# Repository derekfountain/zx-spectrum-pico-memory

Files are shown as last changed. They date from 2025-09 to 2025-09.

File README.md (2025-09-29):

# zx-spectrum-pico-memory

## A Microcontroller-based Lower Memory Implementation for the ZX Spectrum

This project replaces the 16K of lower memory in the ZX Spectrum with a Raspberry Pi Pico2. The RP2350
microcontoller on the Pico is programmed to emulate the original MK4116 DRAM ICs, and responds to reads
and writes from the Z80 CPU and the Spectrum's ULA support chip in the same way the original memory
does. It's not a cycle-perfect implementation, as I'll discuss, and to be honest it's of limited
practical use in this age of cheap SRAM based memory modules. But it was an interesting project, both
from a ZX point of view, and that of pushing the Pico to its limits.

### History

The original work on this project was done by myself and Andrew Menadue in 2022. Andrew designed the board
for the RP2040-based Raspberrry Pi Pico, and that work is still in
<a href="https://github.com/blackjetrock/zx-spectrum-pico-memory">his repository</a>. In late 2022 it
defeated us, the RP2040 just couldn't go fast enough to match 150ns silicon. I picked the project up
again in summer 2025 and had another look at it. Still unable to get it working, I changed it to use
the RP2350-based Pico2, and, that being a faster and more easily overclockable device, was able to
do the task. Just.

## The Technical Challenge

The MK4116 DRAM ICs in the ZX Spectrum provide the machine's lower 16K of RAM (memory locations 0x4000 to
0x7FFF inclusive). This memory area contains the memory used to create the Spectrum's memory mapped
video display (memory area 0x4000 to 0x5AFF inclusive). As such the 16K memory area is used by both the
Z80 CPU and the ULA support chip which is responsible for generating a video display from the memory
area.

The MK4116s used in the Spectrum are rated at 150ns, meaning a single read or write operation will
complete inside 150ns. Although the Z80 doesn't drive the DRAM ICs at their fastest speed, the ULA does.
This is because the ULA was tuned to generate the video image as quickly as possible, thereby not
slowing down the rest of the ZX Spectrum's system. The challenge with this DRAM emulator is to meet the
ULA's speed requirements, as opposed to the much more modest requirements of the Z80.

### Signal Patterns

The MK4116 was designed with a 7 bit address bus to meet physical space requirements and technical
limitations of the day, but to supply 16K of data it needs a 14 bit address bus. The solution to this
problem was to multiplex the address bus. The required 14 bits are sent from the Z80/ULA to the MK4116 in
two phases which make up a grid sort of pattern: the first 7 bits being supplied from the Z80/ULA as the "row"
and the second 7 bits being supplied from the Z80/ULA as the "column". Where the row and column intersect
in the internal MK4116 grid-like store, that's where the required data bit would be read from or written to.

The pattern for the MK4116 emulator to follow is therefore fairly simple: wait for the Row Address Strobe
(RAS) signal to appear, indicating the first 7 bits of the target address are on the address bus, then read
that value and store it. Then wait for the Column Address Strobe (CAS) signal to appear, indicating the
second 7 bits of the target address are on the address bus, then read that value and combine it with the
row value to get the full 14 bit address. Check the WRITE signal to see if the MK4116 should be doing a read
or write, and if it's a write go to the 8 bit data bus to fetch the value being written into the emulated
memory and write it into the Pico's onboard RAM. If the Z80/ULA is doing a read, go and fetch the data byte from
the Pico's onboard memory and put it on the data bus as an output. Once the Z80/ULA's done, go back to the top
and do it again.

The only real complication is that the MK4116 supports a "page mode" which the ULA (but not the Z80)
utilises. This is to support several reads in one go, and runs faster than the normal one-at-a-time mode.
In page mode, the RAS signal (and first 7 bits of the target addresses) are provided, and then the
repeated CAS signals (and associated second 7 bits of the target addresses) are provided one after the
other without ending the original RAS. It's a faster way of reading adjacent MK4116 memory and the ULA uses it to
build the video image as quickly as possible.

### Speed

The MK4116 may be a 1970s design, but it's still presented in silicon, which means it's fast. Not by today's
silicon standards maybe, but by todays CPU standards it is. The RP2040 natively runs at 133MHz, which means
one clock cycle is about 7.5 nanoseconds. The ARM chip runs approximately one instruction per clock cycle (it's
not quite that simple, but it's a rough approximation) which means it can run around 20 instructions in the
150ns access time of the original MK4116. So if the RP2040 was ever going to do everything required of it in
order to produce an accurate emulation, it was going to need to do it in very few instructions.

In pracise, 20 machine code instructions per transaction was never going to be enough to produce an emulation,
even of a simple storage device like the MK4116. Hefty overclocking was always going to be needed. Overclocking
to 270MHz might be fast enough.

It turned out that the RP2040-based Pico just wasn't fast enough. Back in 2022 when this project started I had
a particularly compliant one which overclocked to 360MHz, and that could run fast enough to satisfy the Z80's
requirements, but it was nowhere near fast enough to do the page mode reads the ULA needed. On this basis the
project stalled until 2025 when RP2350-based Pico2s became commonplace. All discussion and timings described
from this point onwards refer to the Pico2.

## Hardware

The hardware board was designed by Andrew Menadue. He did it based on the original Pico, the Pico2 not even
being discussed in 2022. It just fits inside the area of the Spectrum's PCB where the original MK4116s are
installed, and uses a handful of individual header pins to plug into the DRAM sockets.

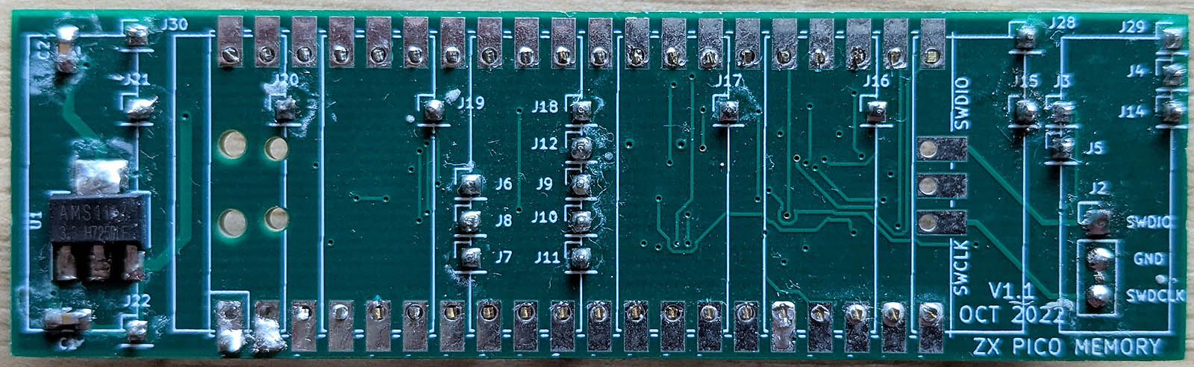
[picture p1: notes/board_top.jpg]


On the top of the board is a voltage regulator and the Raspberry Pi Pico (the photo above doesn't have the
Pico installed). On the underside, inside the area between the Pico's pins,
are 3 level shifters which convert the Spectrum's +5V signals to the Pico's +3V3 voltage. Input signals from 
the Spectrum, like RAS, CAS and the 7 address lines go through level shifters set to a single direction. The
data bus needs to be reversible, so the Pico can both read and write data byte values. The level shifter
which controls the data bus therefore has a Pico-controllable direction toggle.

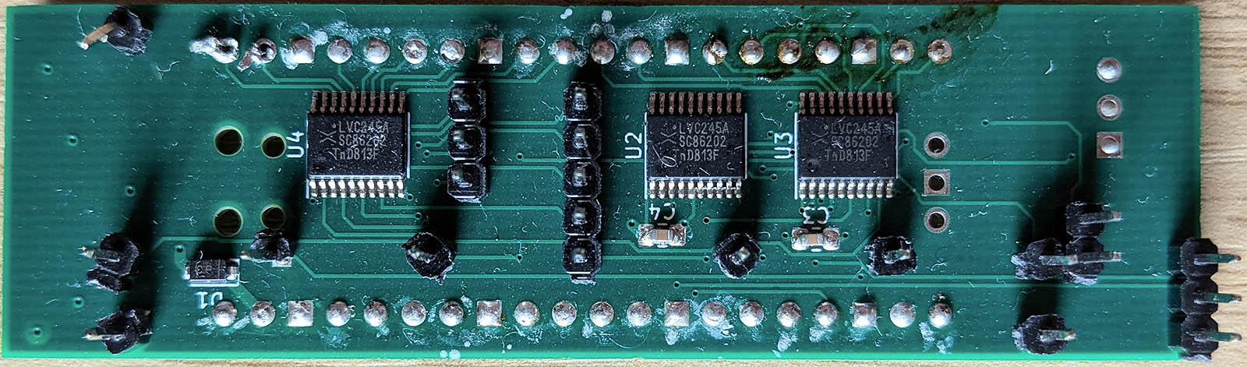
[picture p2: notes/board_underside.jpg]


It's a 4 layer board, and is still a bit cramped. The current version is too tall when the Pico is installed
on it, preventing the Spectrum's keyboard being fitted back in place. If anyone ever has a practical use for
this device it'll probably need redesigning so as to allow the Spectrum to be reassembled. Consider the
current board to be a functioning prototype.

## Software, and the outstanding issue

The software was the main challenge with this project. When Andrew and I started we worked together, writing
code in C. When it started to hit limitations Andrew branched off and started trying to write parts of the
main loop in ARM assembly language. I stuck with C code. We both managed to produce code which would meet
the speed requirements of the Z80:

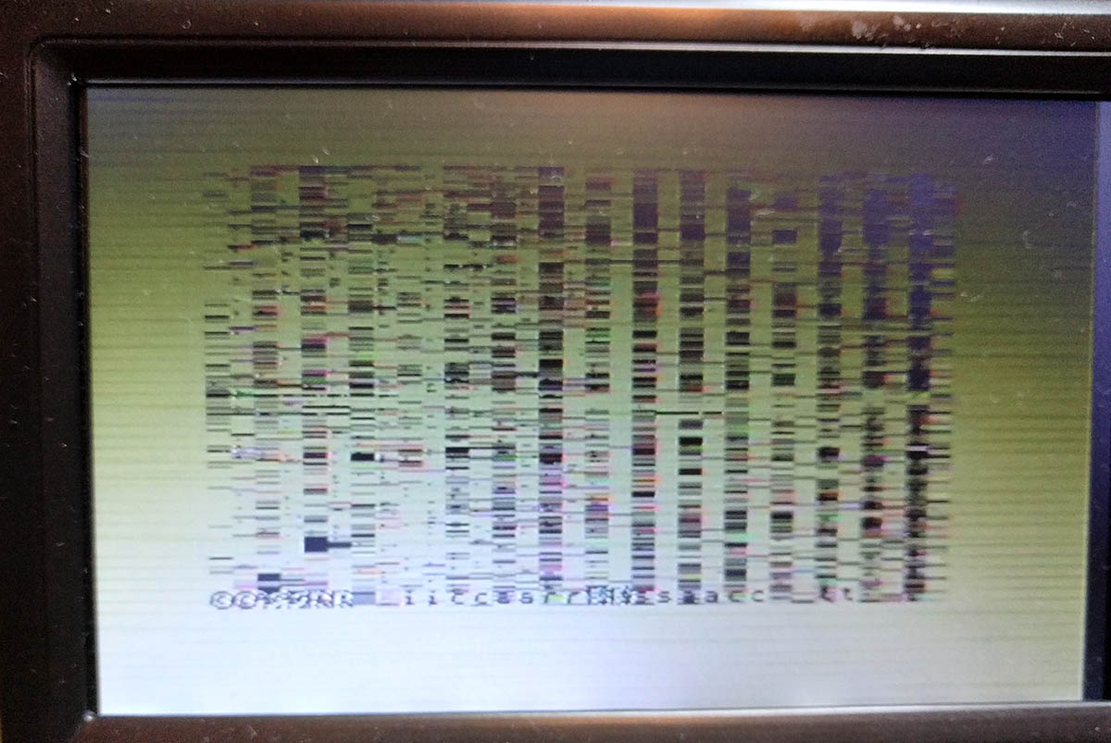
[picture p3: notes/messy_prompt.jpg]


You can just about see the (C) 1982 message peering out from that mess.

But despite a lot of effort, neither of us produced code fast enough to make the Spectrum work properly and
the project stalled for 3 years.

When the Pico2 came out, with its faster cores and higher clock speed I picked up the project and had another
look. I added a few optimisatons, but generally the code I tried on the RP2350 was much the same as that which
was failing on the RP2040 3 years earlier. Only, on the RP2350, with a little more tuning, it worked. Just about.

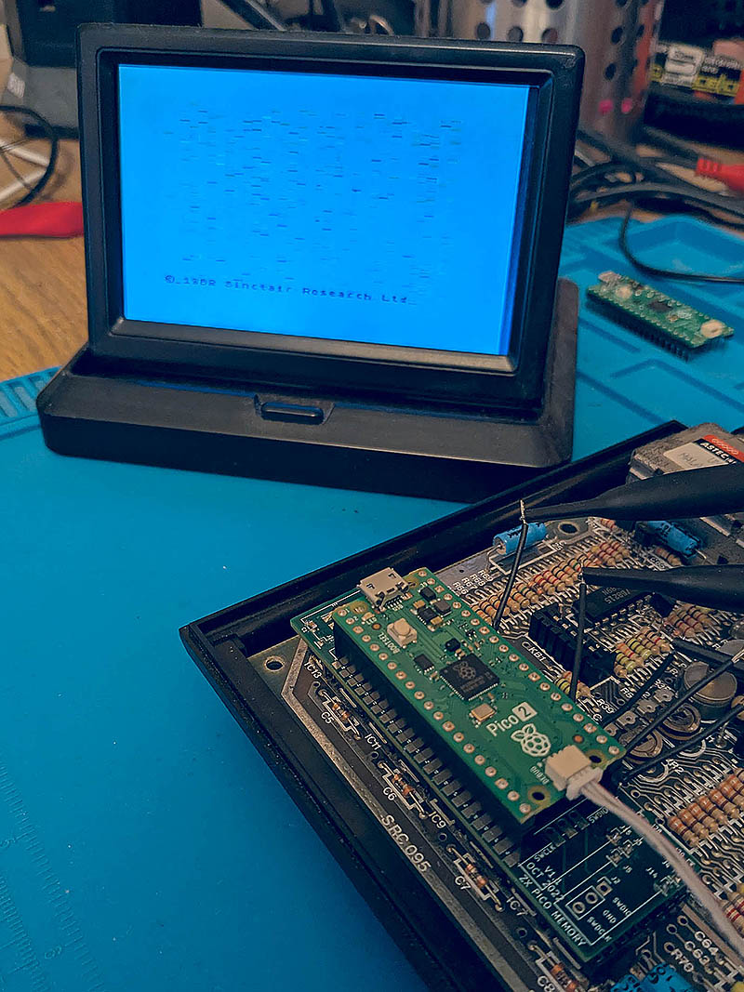
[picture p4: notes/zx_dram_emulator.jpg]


You can see on there are a number of flickering arefacts on the screen. Those are caused by the DRAM emulator
not running quite fast enough to deliver page mode reads to the ULA. Each artefact is the result of a missed
read, the ULA finding essentially random data on its data bus.

The problem is shown on the oscilloscope capture. Yellow is RAS, and that can be seen to go low at the left
side. CAS, in light blue, goes low twice, then RAS goes high again. Those 2 CAS signals indicate 2 data bytes
being read by the ULA, one for pixel data, the other for colour data. That bit works fine. So RAS then goes
high, and then low again. Shortly after RAS goes low the second time (yellow line, centre of the image) CAS
goes high then low again. That's where the ULA is reading the pixel data for the second time, and that's
where the problem is. The gap between RAS going low, and CAS going low, is very tight, about 100ns. At that
point the code needs to spot that RAS has gone low, get the 7 bits of row address from the address bus, then
get back to the top of the loop quickly enough in order to spot that CAS has gone low again. Most times it
can manage it, but just occasionally it misses the CAS. That's when an artefact appears on screen.

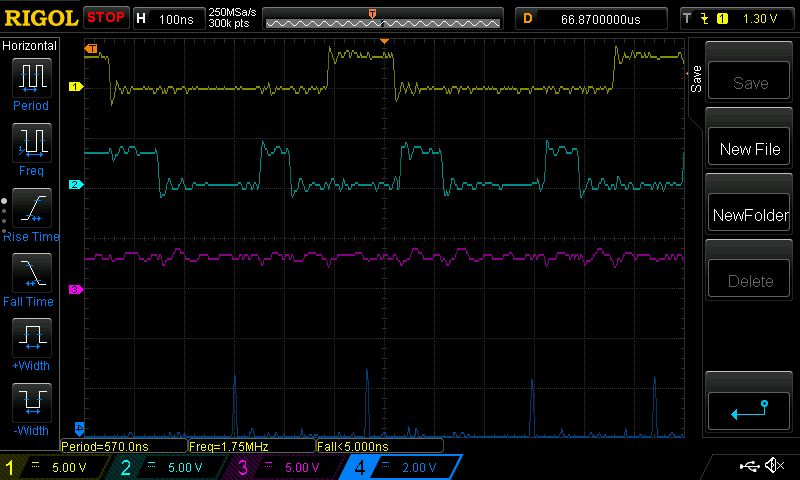
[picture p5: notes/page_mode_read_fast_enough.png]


So it's not quite good enough to use, and the software can't run any faster. PIOs might be an option to get
a bit more speed out of the emulator. Other than that we need to wait for Pico3. :)

[Derek Fountain](https://www.derekfountain.org/), September 2025

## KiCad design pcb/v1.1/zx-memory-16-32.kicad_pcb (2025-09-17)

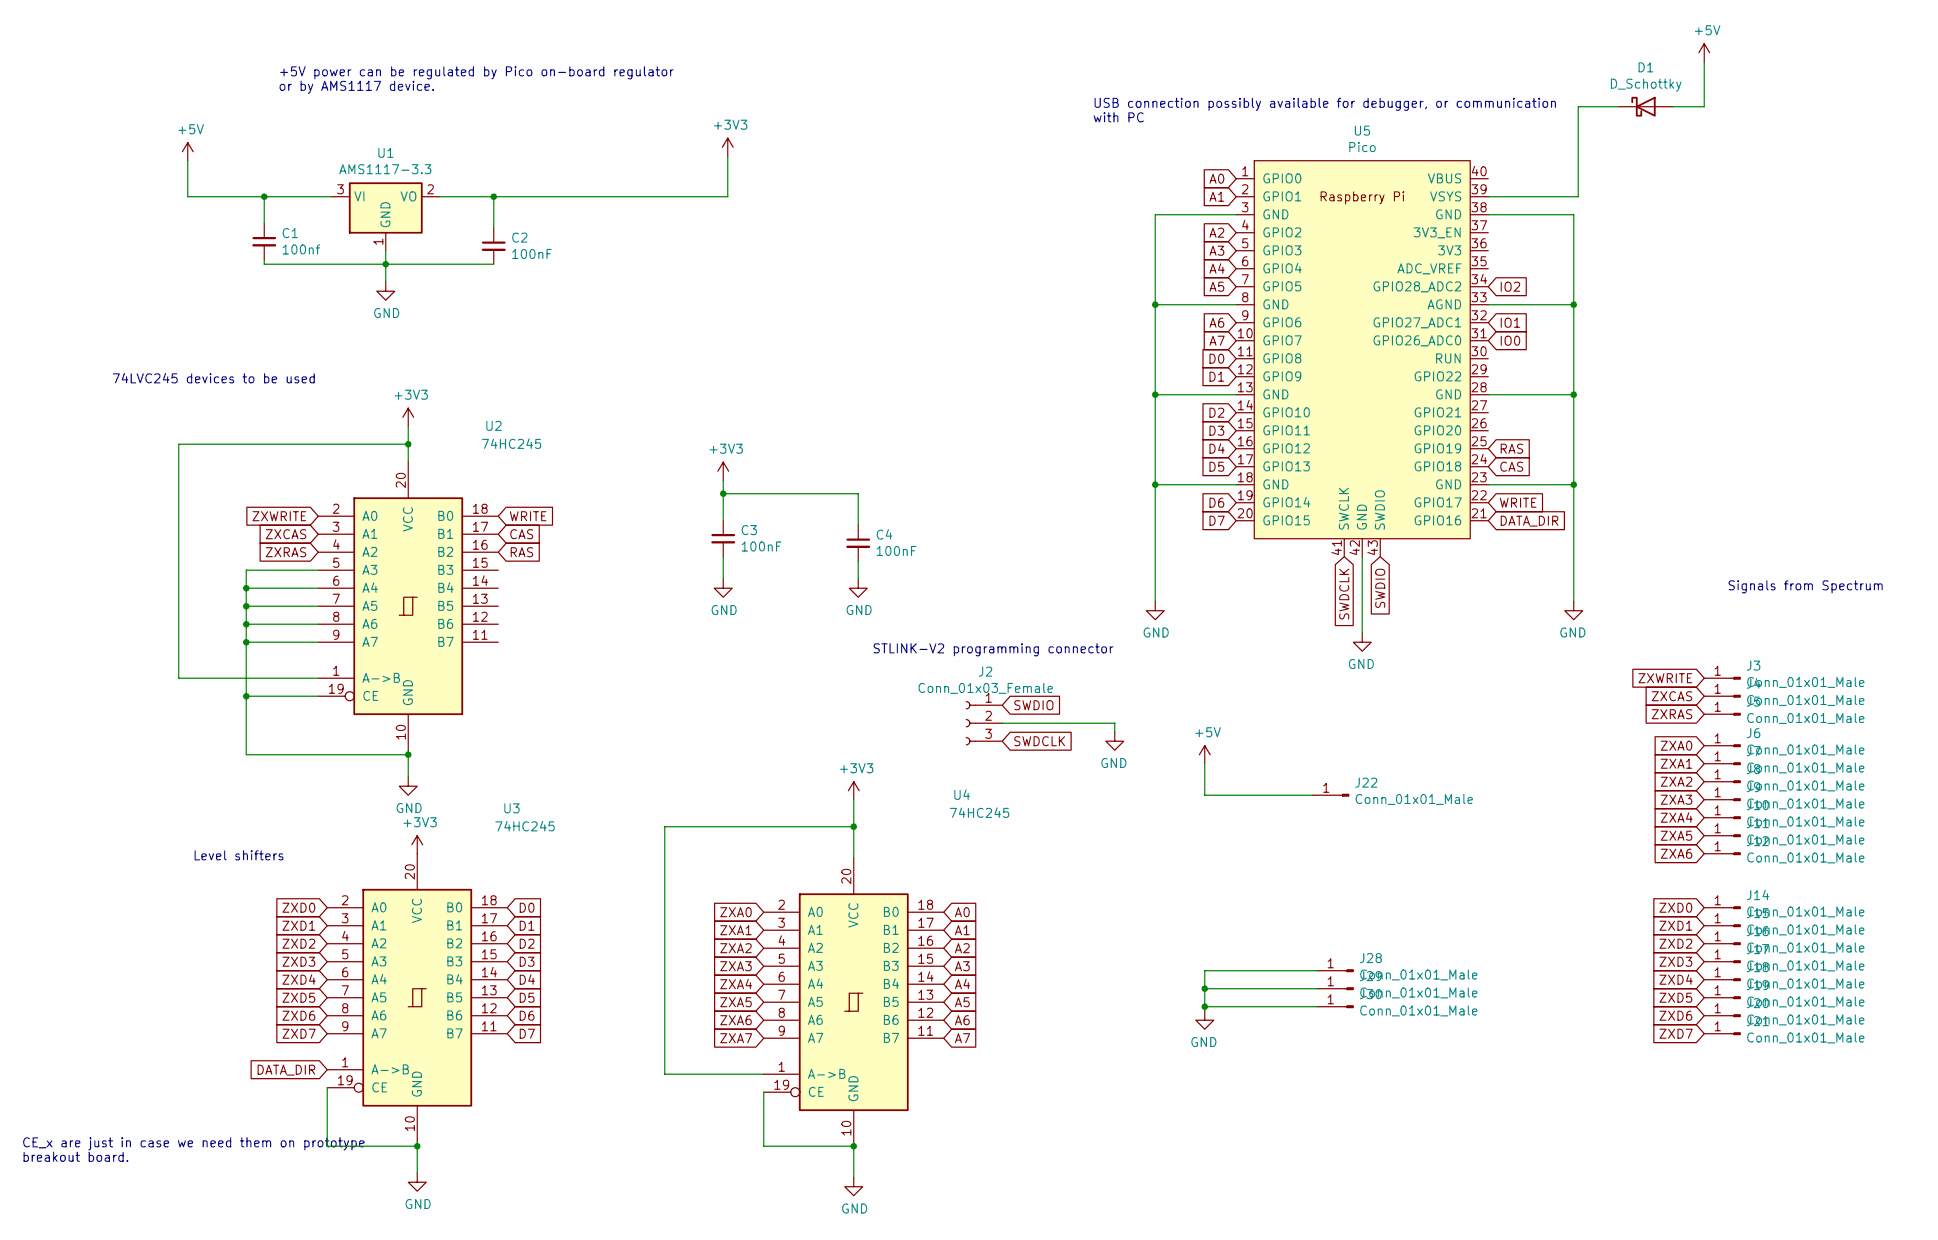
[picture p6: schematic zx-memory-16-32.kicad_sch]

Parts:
C1: 100nf; C_0805_2012Metric_Pad1.18x1.45mm_HandSolder
C2, C3, C4: 100nF; C_0805_2012Metric_Pad1.18x1.45mm_HandSolder
D1: D_Schottky; D_SOD-323_HandSoldering
J2: Conn_01x03_Female; PinHeader_1x03_P2.54mm_Vertical
J3, J4, J5, J6, J7, J8, J9, J10, J11, J12, J14, J15, J16, J17, J18, J19, J20, J21, J22, J28, J29, J30: Conn_01x01_Male; PinHeader_1x01_P2.00mm_Vertical
U1: AMS1117-3.3; SOT-223-3_TabPin2
U2, U3, U4: 74HC245; TSSOP-20_4.4x6.5mm_P0.65mm
U5: Pico; RPi_Pico_SMD_TH

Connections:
+3V3: C2.1, C3.1, C4.1, U1.2 (VO), U2.1 (A->B), U2.20 (VCC), U3.20 (VCC), U4.1 (A->B), U4.20 (VCC)
+5V: C1.1, D1.2 (A), J22.1, U1.3 (VI)
A0: U4.18 (B0), U5.1 (GPIO0)
A1: U4.17 (B1), U5.2 (GPIO1)
A2: U4.16 (B2), U5.4 (GPIO2)
A3: U4.15 (B3), U5.5 (GPIO3)
A4: U4.14 (B4), U5.6 (GPIO4)
A5: U4.13 (B5), U5.7 (GPIO5)
A6: U4.12 (B6), U5.9 (GPIO6)
A7: U4.11 (B7), U5.10 (GPIO7)
CAS: U2.17 (B1), U5.24 (GPIO18)
D0: U3.18 (B0), U5.11 (GPIO8)
D1: U3.17 (B1), U5.12 (GPIO9)
D2: U3.16 (B2), U5.14 (GPIO10)
D3: U3.15 (B3), U5.15 (GPIO11)
D4: U3.14 (B4), U5.16 (GPIO12)
D5: U3.13 (B5), U5.17 (GPIO13)
D6: U3.12 (B6), U5.19 (GPIO14)
D7: U3.11 (B7), U5.20 (GPIO15)
DATA_DIR: U3.1 (A->B), U5.21 (GPIO16)
GND: C1.2, C2.2, C3.2, C4.2, J2.2, J28.1, J29.1, J30.1, U1.1 (GND), U2.5 (A3), U2.6 (A4), U2.7 (A5), U2.8 (A6), U2.9 (A7), U2.10 (GND), U2.19 (CE), U3.10 (GND), U3.19 (CE), U4.10 (GND), U4.19 (CE), U5.3 (GND), U5.8 (GND), U5.13 (GND), U5.18 (GND), U5.23 (GND), U5.28 (GND), U5.33 (AGND), U5.38 (GND), U5.42 (GND)
IO0: U5.31 (GPIO26_ADC0)
IO1: U5.32 (GPIO27_ADC1)
IO2: U5.34 (GPIO28_ADC2)
unnamed: D1.1 (K), U5.39 (VSYS)
RAS: U2.16 (B2), U5.25 (GPIO19)
SWDCLK: J2.3, U5.41 (SWCLK)
SWDIO: J2.1, U5.43 (SWDIO)
WRITE: U2.18 (B0), U5.22 (GPIO17)
ZXA0: J6.1, U4.2 (A0)
ZXA1: J7.1, U4.3 (A1)
ZXA2: J8.1, U4.4 (A2)
ZXA3: J9.1, U4.5 (A3)
ZXA4: J10.1, U4.6 (A4)
ZXA5: J11.1, U4.7 (A5)
ZXA6: J12.1, U4.8 (A6)
ZXCAS: J4.1, U2.3 (A1)
ZXD0: J14.1, U3.2 (A0)
ZXD1: J15.1, U3.3 (A1)
ZXD2: J16.1, U3.4 (A2)
ZXD3: J17.1, U3.5 (A3)
ZXD4: J18.1, U3.6 (A4)
ZXD5: J19.1, U3.7 (A5)
ZXD6: J20.1, U3.8 (A6)
ZXD7: J21.1, U3.9 (A7)
ZXRAS: J5.1, U2.4 (A2)
ZXWRITE: J3.1, U2.2 (A0)

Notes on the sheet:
USB connection possibly available for debugger, or communication with PC
STLINK-V2 programming connector
Signals from Spectrum
+5V power can be regulated by Pico on-board regulator or by AMS1117 device.
CE_x are just in case we need them on prototype breakout board.
Level shifters
74LVC245 devices to be used

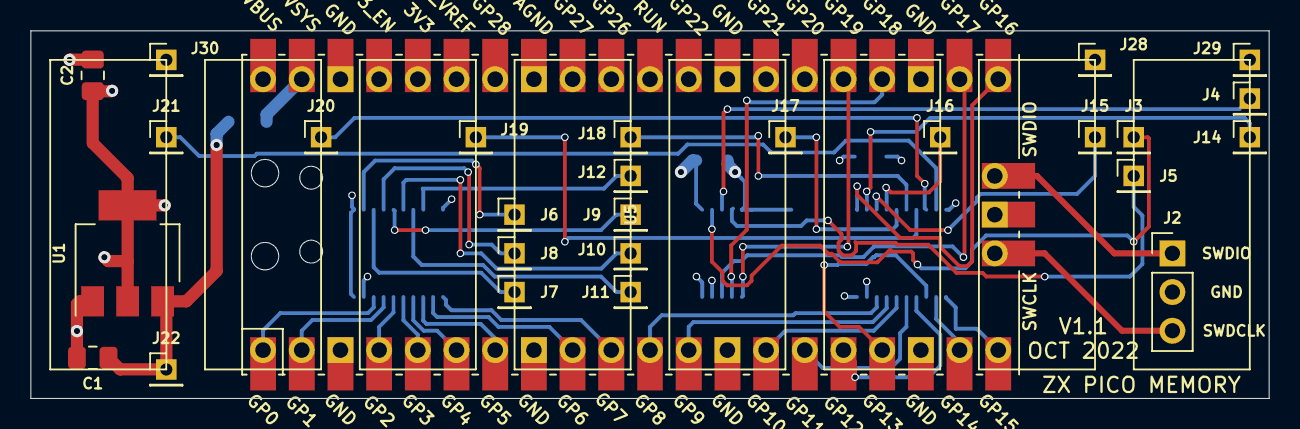
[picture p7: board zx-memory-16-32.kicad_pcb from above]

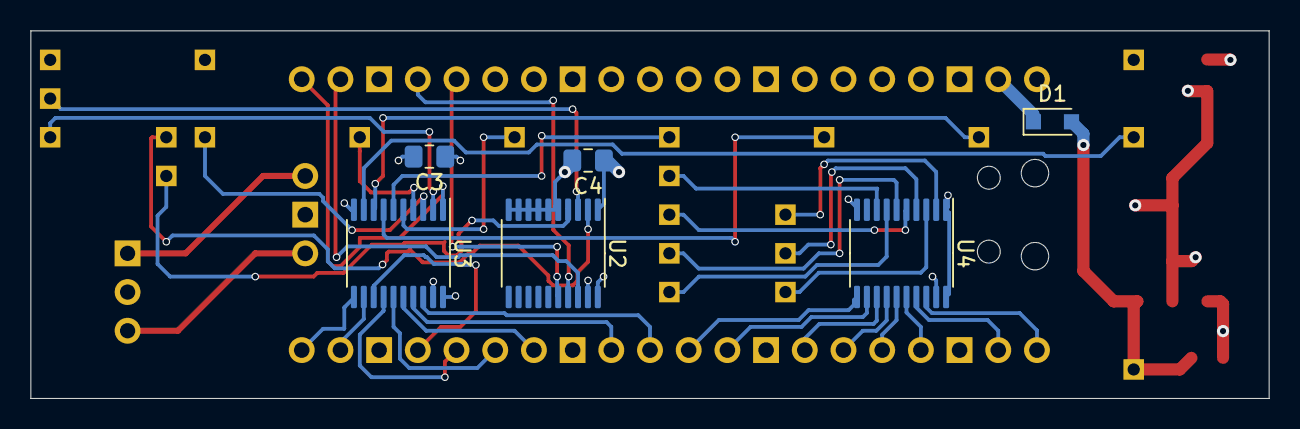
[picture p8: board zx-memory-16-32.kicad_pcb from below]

Board: 4 copper layers, 81.3 x 24.1 mm, 33 parts (6 on the bottom side), 44 nets.

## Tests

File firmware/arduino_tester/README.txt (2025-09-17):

Simulator, runs on an Arduino, outputs RAS, CAS and WR waveforms
in the same pattern as the Spectrum ULA. Only much slower.

Pattern is 4 reads in page mode, pause, 1 refresh, 1 read in cycle mode,
1 write in cycle mode.

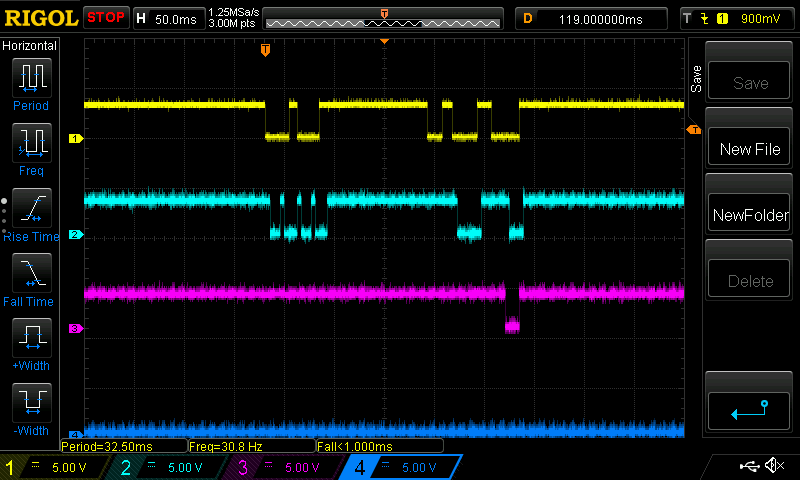
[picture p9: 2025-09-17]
firmware/arduino_tester/sim_output.png

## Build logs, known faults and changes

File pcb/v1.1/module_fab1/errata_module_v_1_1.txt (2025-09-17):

ZX Pico Memory Module V1.1 Errata

1. J22 is 0.1" too low and doesn't line up with the DRAM 5V pin. Bend pin
   to get it to fit.

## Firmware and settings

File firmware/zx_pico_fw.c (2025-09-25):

/*
 * ZX-Pico RAM Emulation, a Raspberry Pi Pico based Spectrum DRAM device
 * Copyright (C) 2025 Derek Fountain, Andrew Menadue
 * 
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
 * You should have received a copy of the GNU General Public License
 * along with this program; if not, write to the Free Software
 * Foundation, Inc., 51 Franklin Street, Fifth Floor, Boston, MA  02110-1301, USA.
 */

/*
 * export PICO_SDK_PATH=/home/derek/BEETLE/Derek/dev/Pico/pico-sdk-v2.x
 *
 * cmake -DPICO_BOARD=pico2 ..
 * cmake -DCMAKE_BUILD_TYPE=Debug -DPICO_BOARD=pico2 ..
 * make -j10
 *
 * sudo openocd -f interface/picoprobe.cfg -f target/rp2040.cfg -c "program ./pico1.elf verify reset exit"
 * sudo openocd -f interface/picoprobe.cfg -f target/rp2040.cfg
 * sudo openocd -f interface/cmsis-dap.cfg -f target/rp2350.cfg -c "adapter speed 5000" -c "program zx_pico_fw.elf verify reset exit"
 * sudo openocd -f interface/cmsis-dap.cfg -f target/rp2350.cfg -c "adapter speed 5000"
 *
 * gdb-multiarch ./pico1.elf
 *  target remote localhost:3333
 *  load
 *  monitor reset init
 *  continue
 */

/* 1 instruction on the 133MHz microprocessor is 7.5ns */
/* 1 instruction on the 200MHz microprocessor is 5.0ns */
/* 1 instruction on the 270MHz microprocessor is 3.7ns */
/* 1 instruction on the 360MHz microprocessor is 2.8ns */

//#define OVERCLOCK 200000
//#define OVERCLOCK 250000
//#define OVERCLOCK 270000
//#define OVERCLOCK 312000
#define OVERCLOCK 360000

/* I think a NOP on the RP2350 runs in half a clock cycle? */
#define _10_NOPS_  __asm volatile ("nop"); \
                   __asm volatile ("nop"); \
                   __asm volatile ("nop"); \
                   __asm volatile ("nop"); \
                   __asm volatile ("nop"); \
                   __asm volatile ("nop"); \
                   __asm volatile ("nop"); \
                   __asm volatile ("nop"); \
                   __asm volatile ("nop"); \
                   __asm volatile ("nop")


#include <stdio.h>
#include <stdint.h>
#include <string.h>
#include <stdlib.h>
#include "pico/stdlib.h"
#include "hardware/gpio.h"
#include "pico/binary_info.h"
#include "hardware/clocks.h"
#include "hardware/vreg.h"
#include "pico/multicore.h"

const uint8_t LED_PIN = PICO_DEFAULT_LED_PIN;

/* These pin values are the GPxx ones in green background on the pinout diagram */

/* Lowest 7 bits in the result from gpio_get_all() */
const uint8_t A0_GP         = 0;
const uint8_t A1_GP         = 1;
const uint8_t A2_GP         = 2;
const uint8_t A3_GP         = 3;
const uint8_t A4_GP         = 4;
const uint8_t A5_GP         = 5;
const uint8_t A6_GP         = 6;
/* A7 is currently unused but it's on the hardware design in case we ever need it */

const uint8_t D0_GP         = 8;
const uint8_t D1_GP         = 9;
const uint8_t D2_GP         = 10;
const uint8_t D3_GP         = 11;
const uint8_t D4_GP         = 12;
const uint8_t D5_GP         = 13;
const uint8_t D6_GP         = 14;
const uint8_t D7_GP         = 15;

const uint8_t RAS_GP        = 19;  /* GP19, pin 25 on Pico, 5th bottom one, on the right side */
const uint8_t CAS_GP        = 18;  /* GP18, pin 24 on Pico, 4th bottom one, on the right side */
const uint8_t WR_GP         = 17;  /* GP17, pin 22 on Pico, 2nd bottom one, on the right side */
const uint8_t DIR_GP        = 16;  /* GP16, pin 21 on Pico, bottom one, on the right side */

/* Keep the address bus in the lowest GPIOs so no rotation is required to read it */
const uint32_t ADDR_GP_MASK = (1<<A0_GP |
                               1<<A1_GP |
                               1<<A2_GP |
                               1<<A3_GP |
                               1<<A4_GP |
                               1<<A5_GP |
                               1<<A6_GP);

const uint32_t DBUS_GP_MASK = (1<<D0_GP |
                               1<<D1_GP |
                               1<<D2_GP |
                               1<<D3_GP |
                               1<<D4_GP |
                               1<<D5_GP |
                               1<<D6_GP |
                               1<<D7_GP);
const uint8_t  DBUS_ROTATE   = 8;

const uint32_t RAS_GP_MASK   = (1<<RAS_GP);
const uint32_t CAS_GP_MASK   = (1<<CAS_GP);
const uint32_t WR_GP_MASK    = (1<<WR_GP);
const uint32_t STROBE_MASK   = (RAS_GP_MASK | CAS_GP_MASK);
const uint32_t DIR_GP_MASK   = (1<<DIR_GP);

const uint8_t TEST_INPUT_GP  = 28;  /* Only use one of these */
const uint8_t TEST_OUTPUT_GP = 28;

/* 16K buffer to emulate the DRAM with */
#define STORE_SIZE 16384
uint32_t *store_ptr;

void __time_critical_func(core1_main)( void )
{
}

int main()
{
  bi_decl(bi_program_description("ZX Spectrum Lower memory Pico board binary."));

#ifdef OVERCLOCK
#if OVERCLOCK > 312000
  vreg_set_voltage(VREG_VOLTAGE_1_20);
  sleep_ms(1000);
#endif
#endif

#ifdef OVERCLOCK
  set_sys_clock_khz( OVERCLOCK, 1 );
#endif

  /* All interrupts off */
  irq_set_mask_enabled( 0xFFFFFFFF, 0 );

  /* All our GPIOs are inputs, except... */
  gpio_set_dir_in_masked( 0x1FFFFFFF );

  /* ...the data direction and my result blipper pin, which are outputs from the pico */
  gpio_init(DIR_GP);
  gpio_set_dir(DIR_GP, GPIO_OUT);
  gpio_set_slew_rate(DIR_GP, GPIO_SLEW_RATE_FAST);
  gpio_set_drive_strength(DIR_GP, GPIO_DRIVE_STRENGTH_12MA);
	
  gpio_init(TEST_OUTPUT_GP);
  gpio_set_dir(TEST_OUTPUT_GP, GPIO_OUT);
  gpio_put(TEST_OUTPUT_GP, 0);
  gpio_set_slew_rate(TEST_OUTPUT_GP, GPIO_SLEW_RATE_FAST);
  gpio_set_drive_strength(TEST_OUTPUT_GP, GPIO_DRIVE_STRENGTH_12MA);

#if 0
  gpio_init(LED_PIN);
  gpio_set_dir(LED_PIN, GPIO_OUT);
  int signal;
  for( signal=0; signal<2; signal++ )
  {
    gpio_put(LED_PIN, 1);
    busy_wait_us_32(250000);
    gpio_put(LED_PIN, 0);
    busy_wait_us_32(250000);
  }
  gpio_put(LED_PIN, 1);
#endif

  /* Pull the buses to zeroes */
  gpio_init( A0_GP ); gpio_set_dir(A0_GP, GPIO_IN); gpio_pull_down( A0_GP );
  gpio_init( A1_GP ); gpio_set_dir(A1_GP, GPIO_IN); gpio_pull_down( A1_GP );
  gpio_init( A2_GP ); gpio_set_dir(A2_GP, GPIO_IN); gpio_pull_down( A2_GP );
  gpio_init( A3_GP ); gpio_set_dir(A3_GP, GPIO_IN); gpio_pull_down( A3_GP );
  gpio_init( A4_GP ); gpio_set_dir(A4_GP, GPIO_IN); gpio_pull_down( A4_GP );
  gpio_init( A5_GP ); gpio_set_dir(A5_GP, GPIO_IN); gpio_pull_down( A5_GP );
  gpio_init( A6_GP ); gpio_set_dir(A6_GP, GPIO_IN); gpio_pull_down( A6_GP );

  /* Init data bus GPIOs. D0 comes from IC6 on the ZX PCB */
  gpio_init( D0_GP );
  gpio_init( D1_GP );
  gpio_init( D2_GP );
  gpio_init( D3_GP );
  gpio_init( D4_GP );
  gpio_init( D5_GP );
  gpio_init( D6_GP );
  gpio_init( D7_GP );

  /* The control signals are active low, so pull them high */
  gpio_init( RAS_GP ); gpio_set_dir(RAS_GP, GPIO_IN); gpio_pull_up( RAS_GP );
  gpio_init( CAS_GP ); gpio_set_dir(CAS_GP, GPIO_IN); gpio_pull_up( CAS_GP );
  gpio_init( WR_GP );  gpio_set_dir(WR_GP,  GPIO_IN); gpio_pull_up( WR_GP );

  /*
   * We run with the direction set to ZX->pico unless specifically required otherwise.
   * It's important we don't try to drive the data bus unless the ZX is specifically
   * wanting us to do so (otherwise we'll corrupt the bus when the Z80 or ROM or
   * whatever is putting data on it). So we keep the level shifter in ZX->pico mode
   * unless we want to put our data on the bus.
   */
  gpio_put(DIR_GP, 1);

  /*
   * Malloc a store for the ZX memory. We only need bytes because we only need to store
   * the 8 bits of the data bus, but it's quicker to store the entire GPIO space for each
   * databus read which is 29 bits in a uint32. The unused bits take up room, but that's
   * less inefficient than trying to mask out the ones we need.
   */
  store_ptr = malloc(STORE_SIZE*sizeof(uint32_t));

  /* Init complete, run 2nd core code */
  /* multicore_launch_core1( core1_main ); */

  uint32_t previous_gpios = STROBE_MASK;

  uint32_t gpios_state;
  uint16_t addr_requested = 0;
  while(1)
  {
    /* gpios_state is state of all 29 GPIOs in one value */

    /* This loop escapes in about 35ns after RAS or CAS goes low (RP2350 360MHz) */
    while( (previous_gpios & ( ~((gpios_state = gpio_get_all())) & STROBE_MASK )) == 0 )
      previous_gpios = gpios_state;
  
    /* This condition is 2 instructions */
    if( ((gpios_state & CAS_GP_MASK) == 0) )
    {
      /* CAS low edge found. */

      /* 40ns (RP2350 360MHz) after CAS */

      /*
       * Column address is on the address bus. Add that to the row address we've
       * already got (and already done the multiply on) and we now have the whole
       * address of the relevant data in our store.
       */

      /* gpios_state is from the point CAS went low */
      if( gpios_state & WR_GP_MASK )
      {
	/* 55ns (RP2350 360MHz) after CAS */

	/*
	 * A read. Get the data from store and get it on the bus before
	 * CAS goes back up
	 */
	  
	/* Prime the level shifter to send to the ZX. gpio_put(DIR_GP, 0); required, clr_mask is faster */
	gpio_clr_mask(DIR_GP_MASK);

	/*
	 * Switch the data bus GPIOs to point towards the ZX - we do this last to prevent
	 * pico outputs driving the shifter while that's still in output mode
	 */
	gpio_set_dir_out_masked( DBUS_GP_MASK );

	/* 70ns (RP2350 360MHz) after CAS */

	/* Put the stored value on the output data bus - this is the slow bit */
	gpio_put_masked( DBUS_GP_MASK, *(store_ptr+(addr_requested + (uint8_t)(gpios_state & ADDR_GP_MASK))) );

        /* Data is available, 100ns (RP2350 360MHz) after CAS */
       
	/*
	 * Wait for RAS or CAS to go high indicating ZX has picked up the data. When it's the
	 * ULA doing the pairs of video data reads in page mode it's RAS I need to look for here.
	 * This sets the previous_gpios value, then uses a continue to get back to the top.
	 * This skips the drop down to the bottom and the assignment to previous_gpios that's
	 * down there. It's very slightly quicker doing it this way.
	 */
	while( ((previous_gpios=gpio_get_all()) & STROBE_MASK) == 0 );

	/* Switch the data bus GPIOs back to pointing from ZX toward the pico */
	gpio_set_dir_in_masked( DBUS_GP_MASK );

	/* Put the level shifters back to reading from the ZX */
	gpio_set_mask(DIR_GP_MASK);

	/*
	 * RAS or CAS has gone up showing ZX has collected our data. At this point
	 * in page mode CAS is just about to go low again. Not much time, we need to
	 * get back to the top of the loop and pick up the next column address which
	 * is going on the bus just about now.
	 */
	continue;
      }
      else
      {
	/*
	 * A write. We already have the data from the bus, so store it.
	 * We had the row address, now we have the column address as well.
	 *
	 * The ULA doesn't do writes, only the Z80. The Z80 runs at a much less
	 * demanding speed than the ULA, so timings here don't matter too much
	 *
	 * RAS goes low, then around 300ns later CAS goes low. This point is about
	 * 75ns after the CAS.
	 */

	/* Store the entire value from the GPIOs, masking is done on the read cycle */
        addr_requested += (uint8_t)(gpios_state & ADDR_GP_MASK);
	*(store_ptr+addr_requested) = gpios_state;

	/* 90ns (RP2350 360MHz) after CAS, the write is complete */
      }

    }
    else if( (gpios_state & RAS_GP_MASK) == 0 )
    {
      /* RAS was high and it's gone low - there's a new row value on the address bus */
      
      /* 50ns (RP2350 360MHz) after RAS */

      /*
       * Pick up the address bus value.
       */
      addr_requested = (uint16_t)(128 * (uint8_t)(gpios_state & ADDR_GP_MASK));
    
      /*
       * 60ns (RP2350 360MHz) after RAS.
       *
       * We've got the row part of the address, now loop back to the top
       * and wait for CAS to go low.
       */
    }

    previous_gpios = gpios_state & STROBE_MASK;

  } /* Infinite loop */

}



#if 0
/* Blip the result pin, shows on scope */
gpio_put( TEST_OUTPUT_GP, 1 ); busy_wait_us_32(5);
gpio_put( TEST_OUTPUT_GP, 0 ); busy_wait_us_32(5);

gpio_put( TEST_OUTPUT_GP, 1 ); busy_wait_us_32(1000);
gpio_put( TEST_OUTPUT_GP, 0 ); busy_wait_us_32(1000);
__asm volatile ("nop");


gpio_put( TEST_OUTPUT_GP, 1 );
__asm volatile ("nop");
gpio_put( TEST_OUTPUT_GP, 0 );

#endif

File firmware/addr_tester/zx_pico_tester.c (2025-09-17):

#define RECORD_MODE 1

#if RECORD_MODE
#define USE_STDIO 0
#define OVERCLOCK 270000
#else
#define USE_STDIO 1
#endif

#include <stdio.h>
#include <stdint.h>
#include <string.h>
#include <stdlib.h>
#include "pico/stdlib.h"
#include "hardware/gpio.h"
#include "pico/binary_info.h"
#include "hardware/vreg.h"
#include <hardware/sync.h>
#include <hardware/flash.h>

const uint8_t LED_PIN = PICO_DEFAULT_LED_PIN;

/* These pin values are the GPxx ones in green background on the pinout diagram */

/* Lowest 7 bits in the result from gpio_get_all() */
const uint8_t A0_GP         = 0;
const uint8_t A1_GP         = 1;
const uint8_t A2_GP         = 2;
const uint8_t A3_GP         = 3;
const uint8_t A4_GP         = 4;
const uint8_t A5_GP         = 5;
const uint8_t A6_GP         = 6;
/* A7 is currently unused but it's on the hardware design in case we ever need it */

const uint8_t RAS_GP        = 19;  /* GP19, pin 25 on Pico, 5th bottom one, on the right side */
const uint8_t CAS_GP        = 18;  /* GP18, pin 24 on Pico, 4th bottom one, on the right side */
const uint8_t WR_GP         = 17;  /* GP17, pin 22 on Pico, 2nd bottom one, on the right side */

/* Keep the address bus in the lowest GPIOs so no rotation is required to read it */
const uint32_t ADDR_GP_MASK = (1<<A0_GP |
                               1<<A1_GP |
                               1<<A2_GP |
                               1<<A3_GP |
                               1<<A4_GP |
                               1<<A5_GP |
                               1<<A6_GP);

const uint32_t RAS_GP_MASK   = (1<<RAS_GP);
const uint32_t CAS_GP_MASK   = (1<<CAS_GP);
const uint32_t WR_GP_MASK    = (1<<WR_GP);
const uint32_t STROBE_MASK   = (RAS_GP_MASK | CAS_GP_MASK);

const uint8_t TEST_OUTPUT_GP  = 28;
const uint8_t SWITCH_INPUT_GP = 15;

typedef struct
{
  uint8_t  ras_addr;
  uint8_t  cas_addr;
  uint8_t  wr;
} TRACE_ENTRY;
const uint32_t NUM_TRACE_ENTRIES = 50000;
const uint32_t STORE_SIZE        = NUM_TRACE_ENTRIES*sizeof(TRACE_ENTRY);

void dump_trace(void)
{
#if USE_STDIO
  stdio_init_all();

  while(1)
  {
    TRACE_ENTRY *trace_table = (TRACE_ENTRY*)(XIP_BASE+0x10000);
    uint32_t trace_index;

    printf("Trace table start\n");
    printf("=================\n");
    for(trace_index=0; trace_index<NUM_TRACE_ENTRIES; trace_index++)
    {
      if( (trace_table+trace_index)->wr == 0xFF )
	break;

      printf("%06d: RAS addr: 0x%02X, CAS addr: 0x%02X, Addr: 0x%04X, WR: %s\n",
	     trace_index,
	     (trace_table+trace_index)->ras_addr,
	     (trace_table+trace_index)->cas_addr,
	     (trace_table+trace_index)->ras_addr*128 + (trace_table+trace_index)->cas_addr,
	     (trace_table+trace_index)->wr ? "RD" : "WR");
    }
    printf("Trace table end\n");
    printf("===============\n");
    stdio_flush();
    sleep_ms(10*1000);
  }
#endif

  while(1)
  {
    gpio_put(LED_PIN, 1); busy_wait_us_32(1000000);
    gpio_put(LED_PIN, 0); busy_wait_us_32(1000000);
  }
}

int main()
{
  bi_decl(bi_program_description("ZX Spectrum Address Bus Tester binary."));

  /* Mustn't destroy a trace by overwriting it, default to showing whatever's there */
  gpio_init( SWITCH_INPUT_GP ); gpio_set_dir(SWITCH_INPUT_GP, GPIO_IN); gpio_pull_down( SWITCH_INPUT_GP );
  if( gpio_get(SWITCH_INPUT_GP) == 0 )
  {
    dump_trace();
  }

#ifdef OVERCLOCK
  set_sys_clock_khz( OVERCLOCK, 1 );
#endif

#if USE_STDIO
  stdio_init_all();
#endif

  /* All interrupts off if we're not using the USB */
#if !USE_STDIO
  irq_set_mask_enabled( 0xFFFFFFFF, 0 );
#endif

  /* All our GPIOs are inputs, except... */
  gpio_set_dir_in_masked( 0x1FFFFFFF );

  /* ...my result blipper pin, which are outputs from the pico */
  gpio_init(TEST_OUTPUT_GP);
  gpio_set_dir(TEST_OUTPUT_GP, GPIO_OUT);
  gpio_put(TEST_OUTPUT_GP, 0);

  /* Pull the buses to zeroes */
  gpio_init( A0_GP ); gpio_set_dir(A0_GP, GPIO_IN); gpio_pull_down( A0_GP );
  gpio_init( A1_GP ); gpio_set_dir(A1_GP, GPIO_IN); gpio_pull_down( A1_GP );
  gpio_init( A2_GP ); gpio_set_dir(A2_GP, GPIO_IN); gpio_pull_down( A2_GP );
  gpio_init( A3_GP ); gpio_set_dir(A3_GP, GPIO_IN); gpio_pull_down( A3_GP );
  gpio_init( A4_GP ); gpio_set_dir(A4_GP, GPIO_IN); gpio_pull_down( A4_GP );
  gpio_init( A5_GP ); gpio_set_dir(A5_GP, GPIO_IN); gpio_pull_down( A5_GP );
  gpio_init( A6_GP ); gpio_set_dir(A6_GP, GPIO_IN); gpio_pull_down( A6_GP );

  /* The control signals are active low, so pull them high */
  gpio_init( RAS_GP ); gpio_set_dir(RAS_GP, GPIO_IN); gpio_pull_up( RAS_GP );
  gpio_init( CAS_GP ); gpio_set_dir(CAS_GP, GPIO_IN); gpio_pull_up( CAS_GP );
  gpio_init( WR_GP );  gpio_set_dir(WR_GP,  GPIO_IN); gpio_pull_up( WR_GP );

  register TRACE_ENTRY *trace_table = malloc(STORE_SIZE);
  register uint32_t     trace_index = 0;
  for( trace_index=0; trace_index<NUM_TRACE_ENTRIES; trace_index++ )
    (trace_table+trace_index)->wr = 0xFF;

  gpio_init(LED_PIN);
  gpio_set_dir(LED_PIN, GPIO_OUT);
  gpio_put(LED_PIN, 1);

  register uint32_t previous_gpios = STROBE_MASK;
  register uint16_t ras_addr = 0xFFFF;
  register uint32_t gpios_state;
  trace_index = 0;
  while(1)
  {
    /* gpios_state is state of all 29 GPIOs in one value */

    while( (previous_gpios & (~ ((gpios_state = gpio_get_all()) ) & STROBE_MASK )) == 0 )
    {
#if USE_STDIO
      printf("Main loop, GPIOs %08X, gpios_state & STOBE_MASK %08X, saved RAS addr is 0x%04X\n",
	     gpios_state, gpios_state & STROBE_MASK, ras_addr);
      sleep_ms(500);
#endif
      previous_gpios = gpios_state;
    }
#if USE_STDIO
    printf("Escaped main loop, GPIOs %08X\n", gpios_state);
#endif
      gpio_put( TEST_OUTPUT_GP, 1 );
      __asm volatile ("nop");
      __asm volatile ("nop");
      __asm volatile ("nop");
      __asm volatile ("nop");
      __asm volatile ("nop");
      gpio_put( TEST_OUTPUT_GP, 0 );

    if( ((gpios_state & CAS_GP_MASK) == 0) )
    {
      /* CAS low edge found. */

      /* gpios_state is from the point CAS went low */
      if( gpios_state & WR_GP_MASK )
      {
	/* A read */
	(trace_table+trace_index)->wr = 1;  /* WRITE is active low, so keep with that, 1 means read */

	(trace_table+trace_index)->ras_addr = ras_addr;
	(trace_table+trace_index)->cas_addr = (uint8_t)(gpios_state & ADDR_GP_MASK);
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

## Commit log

2025-09-17 add andrew's original PCB design, cleaned a bit and updated to latest kicad
    [zx-memory-16-32-B_Cu.gbr, zx-memory-16-32-B_Mask.gbr, zx-memory-16-32-B_Paste.gbr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]
2025-09-19 remove redundant level shifter direction switching GPIOs
2025-09-19 Replace the wait-for-CAS-to-go-low with a hardcoded NOP sled. Not sure this is useful
    [zx_pico_fw.c]
2025-09-20 build on the Pico2 now working, device doesn't work for Z80 so that's a step backwards
    [zx_pico_fw.c]
2025-09-24 fix small bug in read path, still not working. going to try rp2040 again
    [zx_pico_fw.c]
2025-09-24 overclock rp2350 to 360MHz, z80 now happy, ula timings right, video contents wrong
    [zx_pico_fw.c]
2025-09-25 fix bug on page mode, z80 and ULA now working, quite a bit of video noise
    [zx_pico_fw.c]
2025-09-28 README work, couple of photos

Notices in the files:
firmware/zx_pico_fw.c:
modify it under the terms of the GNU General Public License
